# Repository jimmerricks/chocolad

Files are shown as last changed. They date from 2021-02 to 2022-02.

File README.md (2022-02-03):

# Chocolad

The Chocolad is a WIP 3x5+3 split column stagger keyboard based on the [Corne Chocolate](https://github.com/foostan/crkbd/blob/master/corne-chocolate/doc/buildguide_en.md) and the [chocorne](https://github.com/davidphilipbarr/36keys/tree/master/42Keys/chocorne).

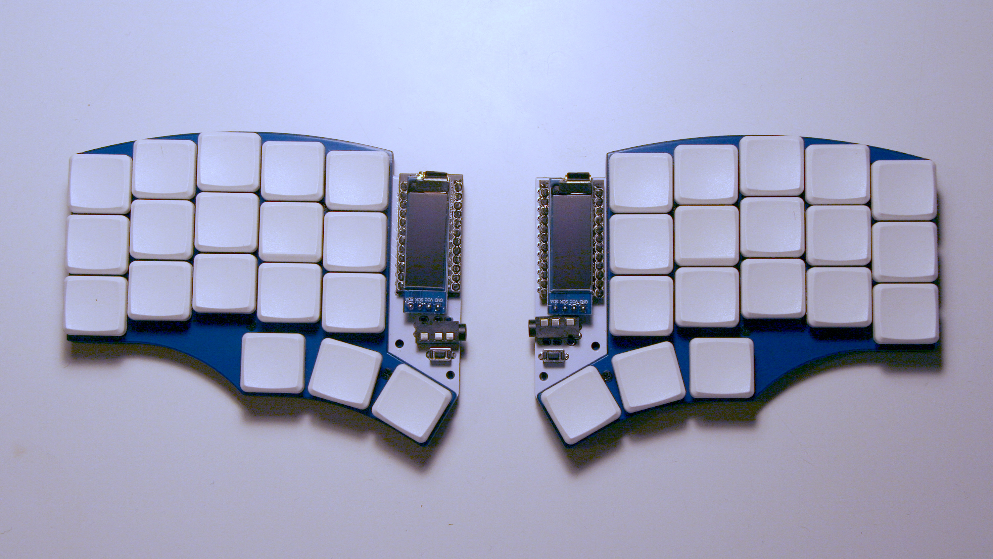
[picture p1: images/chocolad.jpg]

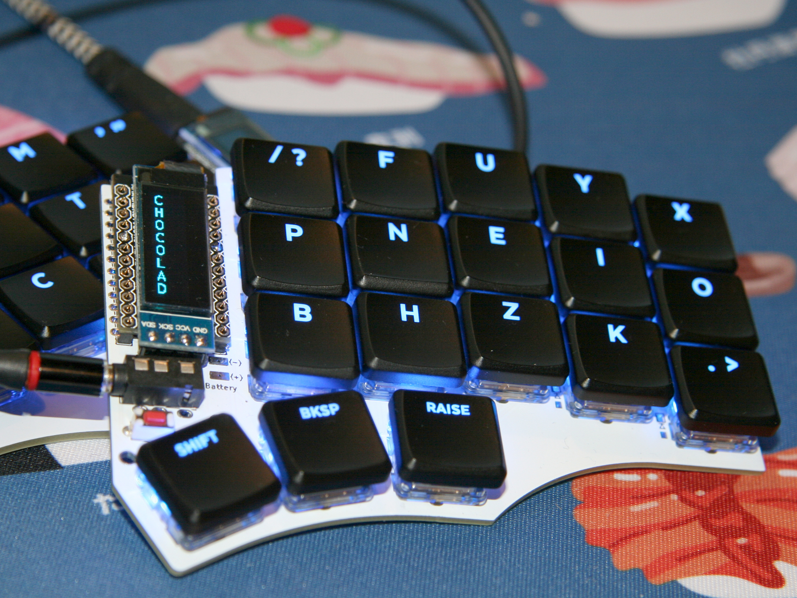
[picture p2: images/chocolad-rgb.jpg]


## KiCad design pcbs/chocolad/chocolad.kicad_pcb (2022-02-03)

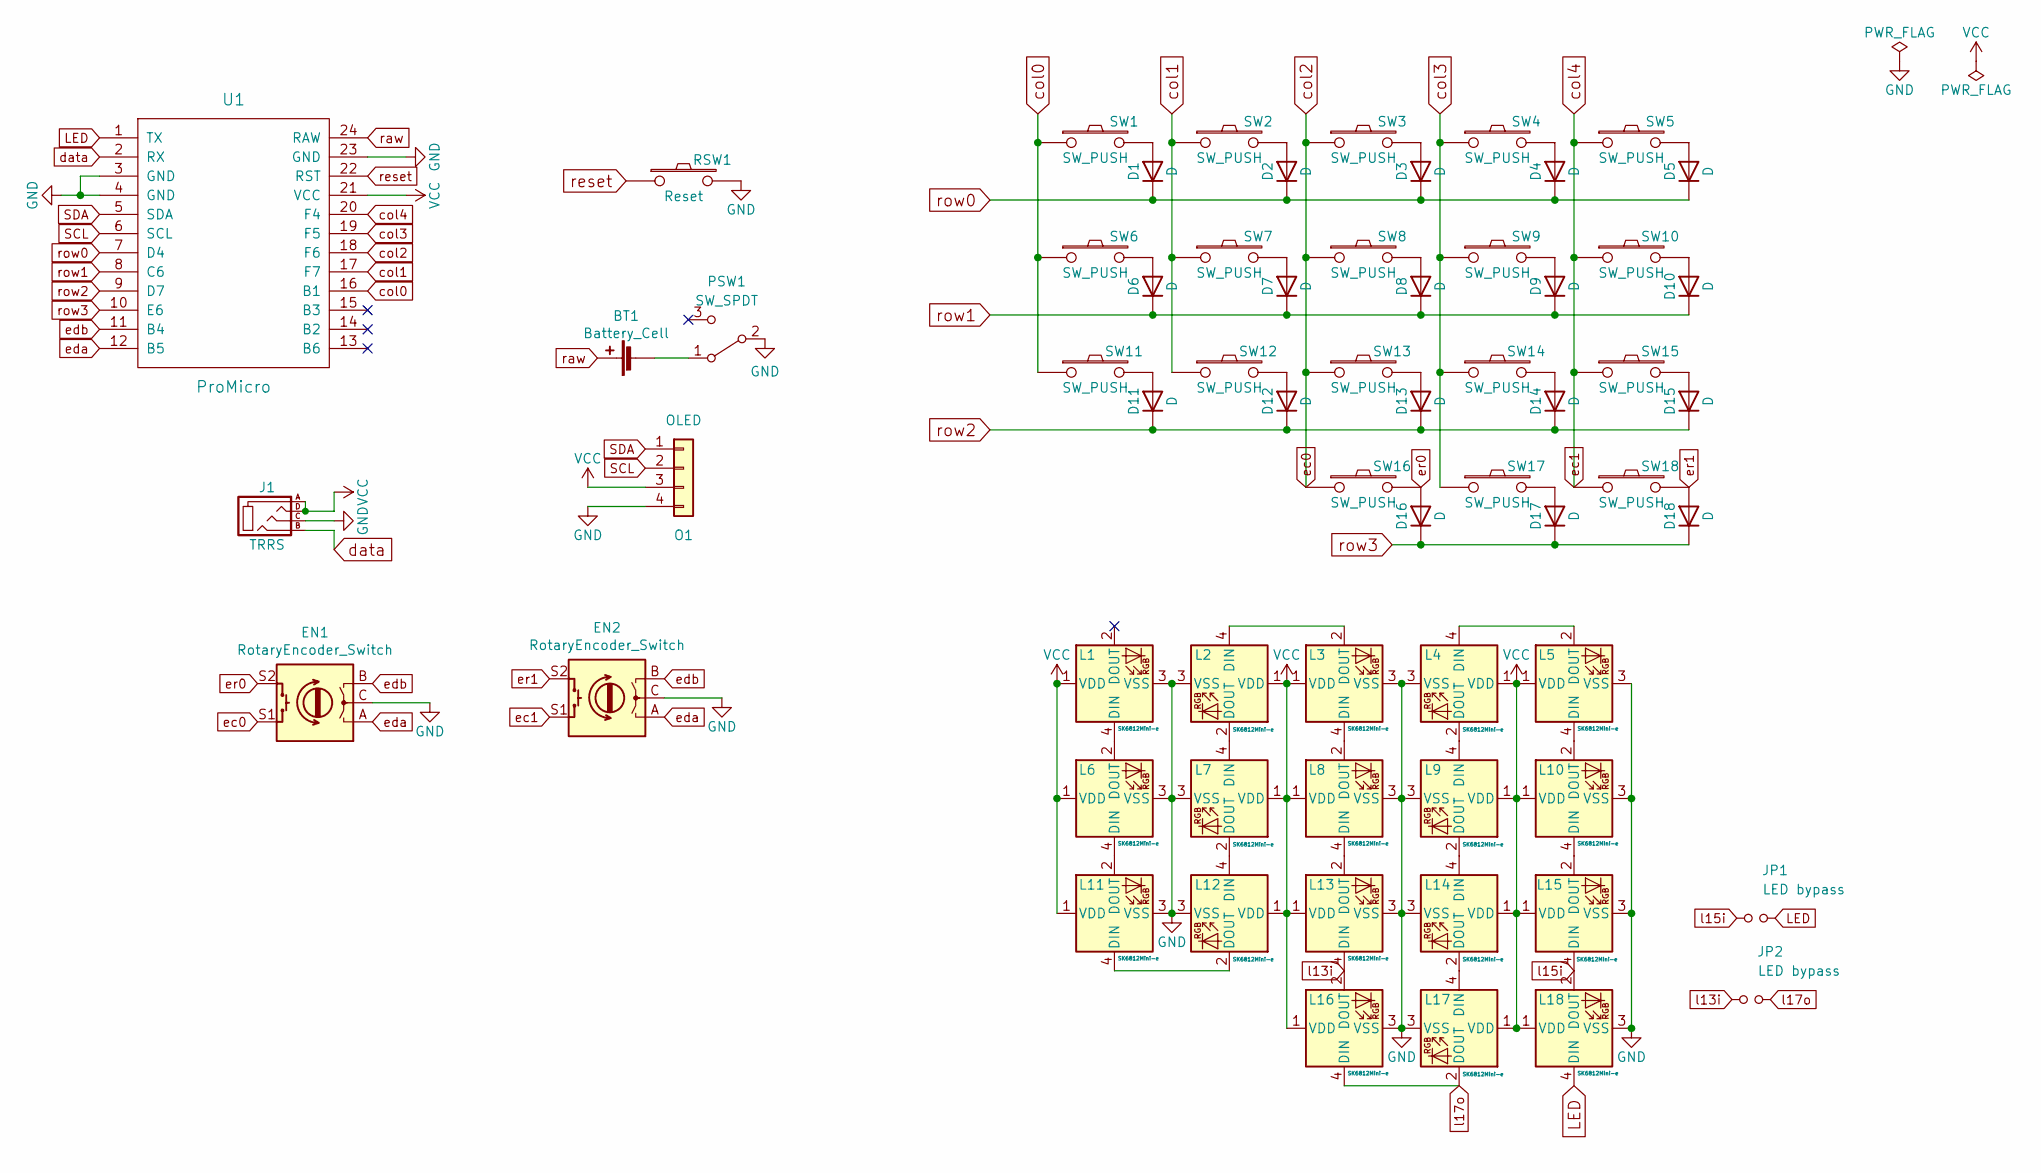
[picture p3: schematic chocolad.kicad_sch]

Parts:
BT1: Battery_Cell; Battery_pads
D1, D2, D3, D4, D5, D6, D7, D8, D9, D10, D11, D12, D13, D14, D15, D16, D17, D18: D; D3_SMD
EN1, EN2: RotaryEncoder_Switch; RotaryEncoder
J1: TRRS
JP1, JP2: LED bypass; Jumper
L1, L2, L3, L4, L5, L6, L7, L8, L9, L10, L11, L12, L13, L14, L15, L16, L17, L18: SK6812Mini-e; SK6812_Mini_E; JLCPCB BOM 0
O1: OLED
PSW1: SW_SPDT; Power
RSW1: Reset
SW1, SW2, SW3, SW4, SW5, SW6, SW7, SW8, SW9, SW10, SW11, SW12, SW13, SW14, SW15, SW16, SW17, SW18: SW_PUSH; Choc
U1: ProMicro

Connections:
GND: EN1.C, EN2.C, J1.C, L1.3 (VSS), L2.3 (VSS), L3.3 (VSS), L4.3 (VSS), L5.3 (VSS), L6.3 (VSS), L7.3 (VSS), L8.3 (VSS), L9.3 (VSS), L10.3 (VSS), L11.3 (VSS), L12.3 (VSS), L13.3 (VSS), L14.3 (VSS), L15.3 (VSS), L16.3 (VSS), L17.3 (VSS), L18.3 (VSS), O1.4, PSW1.2 (B), RSW1.2, U1.3 (GND), U1.4 (GND), U1.23 (GND)
LED: JP1.1, L18.4 (DIN), U1.1 (TX)
unnamed: BT1.2 (-), PSW1.1 (A)
unnamed: D1.2 (A), SW1.2
unnamed: D2.2 (A), SW2.2
unnamed: D3.2 (A), SW3.2
unnamed: D4.2 (A), SW4.2
unnamed: D5.2 (A), SW5.2
unnamed: D6.2 (A), SW6.2
unnamed: D7.2 (A), SW7.2
unnamed: D8.2 (A), SW8.2
unnamed: D9.2 (A), SW9.2
unnamed: D10.2 (A), SW10.2
unnamed: D11.2 (A), SW11.2
unnamed: D12.2 (A), SW12.2
unnamed: D13.2 (A), SW13.2
unnamed: D14.2 (A), SW14.2
unnamed: D15.2 (A), SW15.2
unnamed: D17.2 (A), SW17.2
unnamed: L1.4 (DIN), L6.2 (DOUT)
unnamed: L2.2 (DOUT), L7.4 (DIN)
unnamed: L2.4 (DIN), L3.2 (DOUT)
unnamed: L3.4 (DIN), L8.2 (DOUT)
unnamed: L4.2 (DOUT), L9.4 (DIN)
unnamed: L4.4 (DIN), L5.2 (DOUT)
unnamed: L5.4 (DIN), L10.2 (DOUT)
unnamed: L10.4 (DIN), L15.2 (DOUT)
unnamed: L6.4 (DIN), L11.2 (DOUT)
unnamed: L11.4 (DIN), L12.2 (DOUT)
unnamed: L7.2 (DOUT), L12.4 (DIN)
unnamed: L8.4 (DIN), L13.2 (DOUT)
unnamed: L14.2 (DOUT), L17.4 (DIN)
unnamed: L9.2 (DOUT), L14.4 (DIN)
SCL: O1.2, U1.6 (SCL)
SDA: O1.1, U1.5 (SDA)
VCC: J1.A, J1.D, L1.1 (VDD), L2.1 (VDD), L3.1 (VDD), L4.1 (VDD), L5.1 (VDD), L6.1 (VDD), L7.1 (VDD), L8.1 (VDD), L9.1 (VDD), L10.1 (VDD), L11.1 (VDD), L12.1 (VDD), L13.1 (VDD), L14.1 (VDD), L15.1 (VDD), L16.1 (VDD), L17.1 (VDD), L18.1 (VDD), O1.3, U1.21 (VCC)
col0: SW1.1, SW6.1, SW11.1, U1.16 (B1)
col1: SW2.1, SW7.1, SW12.1, U1.17 (F7)
col2: EN1.S1, SW3.1, SW8.1, SW13.1, SW16.1, U1.18 (F6)
col3: SW4.1, SW9.1, SW14.1, SW17.1, U1.19 (F5)
col4: EN2.S1, SW5.1, SW10.1, SW15.1, SW18.1, U1.20 (F4)
data: J1.B, U1.2 (RX)
eda: EN1.A, EN2.A, U1.12 (B5)
edb: EN1.B, EN2.B, U1.11 (B4)
er0: D16.2 (A), EN1.S2, SW16.2
er1: D18.2 (A), EN2.S2, SW18.2
l13i: JP2.2, L13.4 (DIN), L16.2 (DOUT)
l15i: JP1.2, L15.4 (DIN), L18.2 (DOUT)
l17o: JP2.1, L16.4 (DIN), L17.2 (DOUT)
raw: BT1.1 (+), U1.24 (RAW)
reset: RSW1.1, U1.22 (RST)
row0: D1.1 (K), D2.1 (K), D3.1 (K), D4.1 (K), D5.1 (K), U1.7 (D4)
row1: D6.1 (K), D7.1 (K), D8.1 (K), D9.1 (K), D10.1 (K), U1.8 (C6)
row2: D11.1 (K), D12.1 (K), D13.1 (K), D14.1 (K), D15.1 (K), U1.9 (D7)
row3: D16.1 (K), D17.1 (K), D18.1 (K), U1.10 (E6)

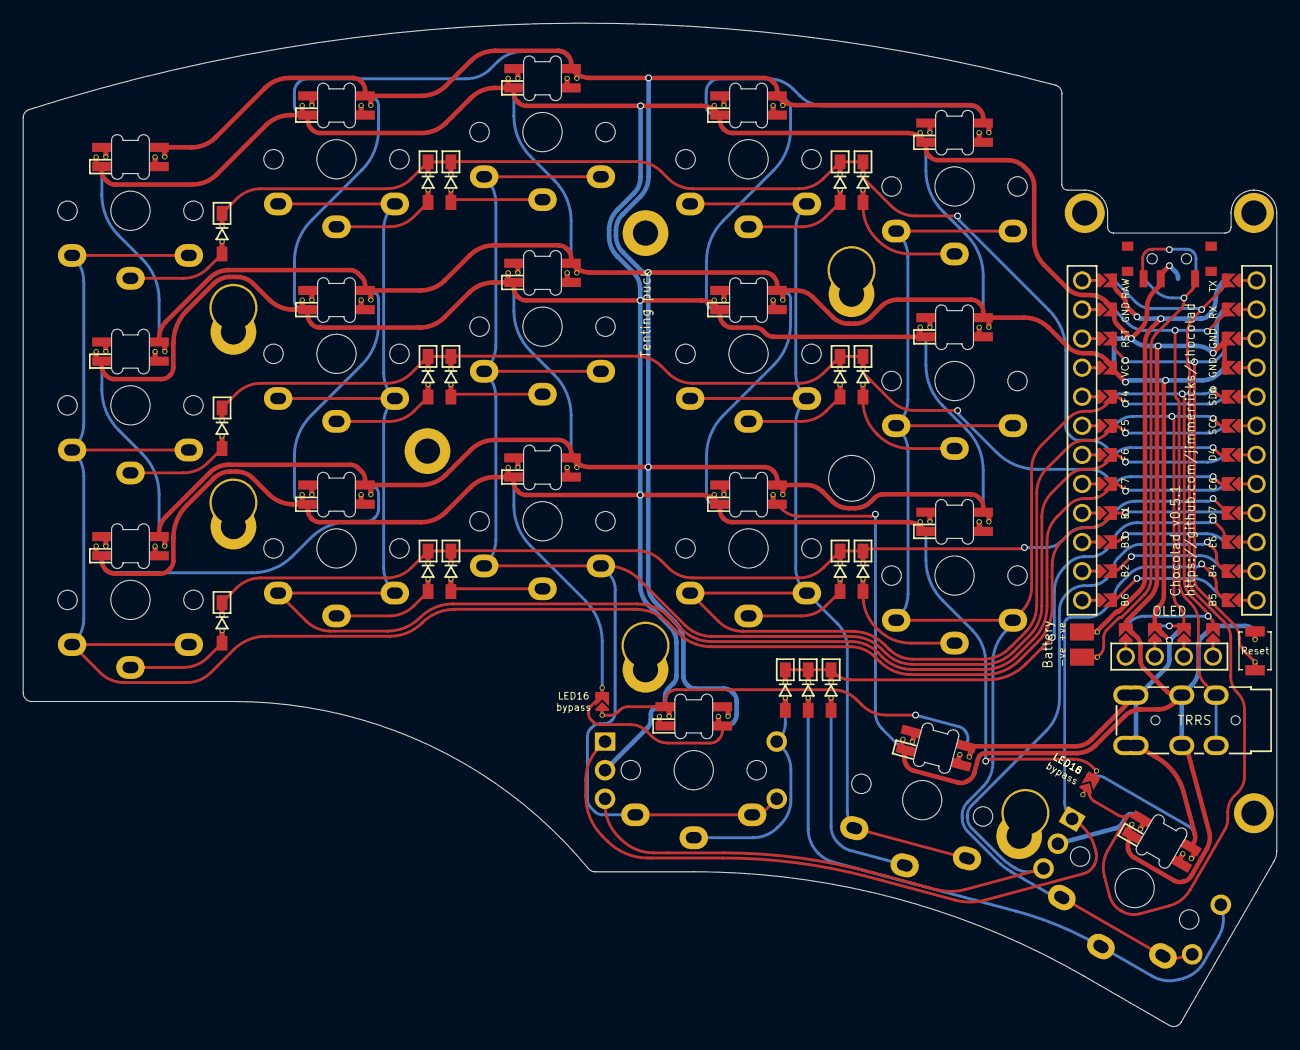
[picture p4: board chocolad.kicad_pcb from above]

Board: 2 copper layers, 109.5 x 87.7 mm, 73 parts (0 on the bottom side), 55 nets.

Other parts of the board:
H1, H2, H3, H5: M2 Hole; M2_double_hole_4mm
H4: M2_double_hole_4mm
PUCK1: SYM_Arrow45_Small; Tenting_puck
Ref**: Val**; M2_hole_3.5mm
Ref**#2, Ref**#3: Val**; M2_hole_3.5mm

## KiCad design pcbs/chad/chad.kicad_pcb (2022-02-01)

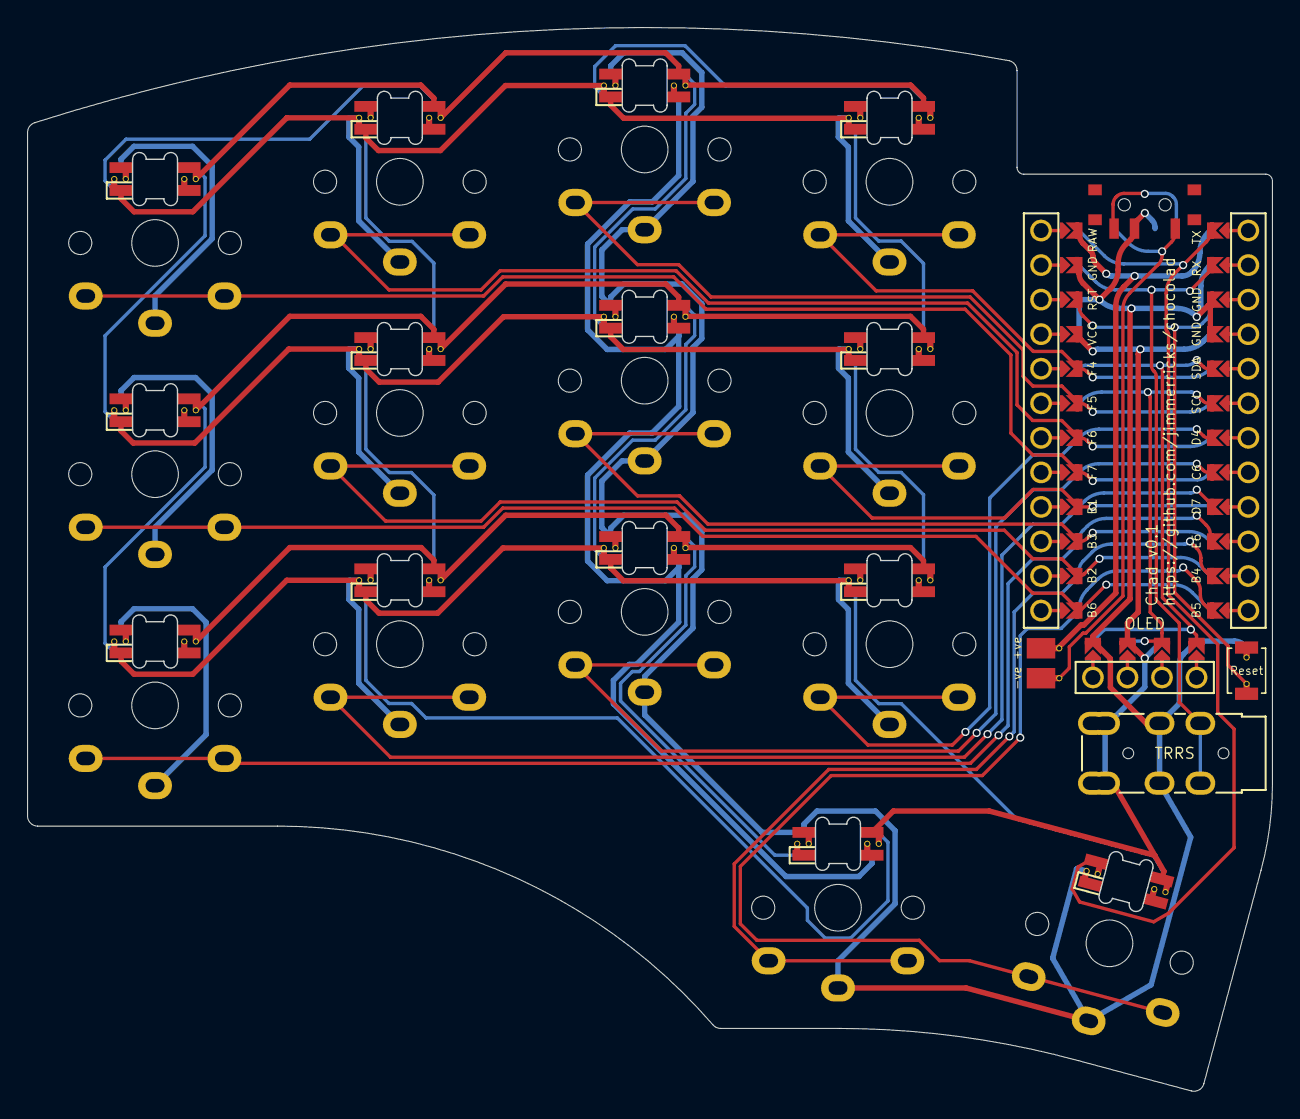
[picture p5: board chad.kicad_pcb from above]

Board: 2 copper layers, 91.5 x 78.2 mm, 34 parts (0 on the bottom side), 36 nets.

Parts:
BT1: Battery_Cell; Battery_pads
J1: TRRS
L1: SK6812Mini-e; SK6812_Mini_E
L2, L3, L4, L5, L6, L7, L8, L9, L10, L11, L12, L13, L14: SK6812Mini-e; SK6812_Mini_E_edit
O1: OLED
PSW1: SW_SPDT; Power
RSW1: Reset
SW1, SW2, SW3, SW4, SW5, SW6, SW7, SW8, SW9, SW10, SW11, SW12, SW13, SW14: SW_PUSH; Choc
U1: ProMicro

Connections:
GND: J1.C, L1.3 (VSS), L2.3 (VSS), L3.3 (VSS), L4.3 (VSS), L5.3 (VSS), L6.3 (VSS), L7.3 (VSS), L8.3 (VSS), L9.3 (VSS), L10.3 (VSS), L11.3 (VSS), L12.3 (VSS), L13.3 (VSS), L14.3 (VSS), O1.4, PSW1.2 (B), RSW1.2, SW1.2, SW2.2, SW3.2, SW4.2, SW5.2, SW6.2, SW7.2, SW8.2, SW9.2, SW10.2, SW11.2, SW12.2, SW13.2, SW14.2, U1.3 (GND), U1.4 (GND), U1.23 (GND)
LED: L14.4 (DIN), U1.1 (TX)
unnamed: BT1.2 (-), PSW1.1 (A)
unnamed: L1.2 (DOUT), L5.4 (DIN)
unnamed: L1.4 (DIN), L2.2 (DOUT)
unnamed: L2.4 (DIN), L6.2 (DOUT)
unnamed: L3.2 (DOUT), L7.4 (DIN)
unnamed: L3.4 (DIN), L4.2 (DOUT)
unnamed: L4.4 (DIN), L8.2 (DOUT)
unnamed: L5.2 (DOUT), L9.4 (DIN)
unnamed: L6.4 (DIN), L10.2 (DOUT)
unnamed: L10.4 (DIN), L13.2 (DOUT)
unnamed: L11.2 (DOUT), L13.4 (DIN)
unnamed: L7.2 (DOUT), L11.4 (DIN)
unnamed: L8.4 (DIN), L12.2 (DOUT)
unnamed: L12.4 (DIN), L14.2 (DOUT)
SCL: O1.2, U1.6 (SCL)
SDA: O1.1, U1.5 (SDA)
VCC: J1.A, J1.D, L1.1 (VDD), L2.1 (VDD), L3.1 (VDD), L4.1 (VDD), L5.1 (VDD), L6.1 (VDD), L7.1 (VDD), L8.1 (VDD), L9.1 (VDD), L10.1 (VDD), L11.1 (VDD), L12.1 (VDD), L13.1 (VDD), L14.1 (VDD), O1.3, U1.21 (VCC)
data: J1.B, U1.2 (RX)
raw: BT1.1 (+), U1.24 (RAW)
reset: RSW1.1, U1.22 (RST)
switch1: SW1.1, U1.17 (F7)
switch2: SW2.1, U1.18 (F6)
switch3: SW3.1, U1.19 (F5)
switch4: SW4.1, U1.20 (F4)
switch5: SW5.1, U1.13 (B6)
switch6: SW6.1, U1.14 (B2)
switch7: SW7.1, U1.15 (B3)
switch8: SW8.1, U1.16 (B1)
switch9: SW9.1, U1.10 (E6)
switch10: SW10.1, U1.9 (D7)
switch11: SW11.1, U1.8 (C6)
switch12: SW12.1, U1.7 (D4)
switch13: SW13.1, U1.11 (B4)
switch14: SW14.1, U1.12 (B5)

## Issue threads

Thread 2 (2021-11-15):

Parts List

drewfowler, 2021-11-15:
Hello Jim! This board looks amazing and I really want to build it. Any chance you have a parts list so that I can order parts before I just order PCBs?

KostkaBrukowa, 2021-11-16:
I looked into the schema and I think you will need:
PCB | 2 pieces |  
Pro Micro | 2 |  
TRRS Jack | 2 |  
Tactile switch | 2 pieces |  
Diode | 36 pieces | Compatible with chip components only
Key switch | 36 pieces | Compatible with Choc (low profile) only
Key-caps | 36 | 1u
OLED module | 2 pieces |  Optional
4 pin headers | 2 |  
4 pin sockets | 2 |  
Cushion rubber | 8 pieces |  
TRS (3 pole) cable | 1 | TRRS (4 pole) cable also available
Micro USB Cable

Taken from here: https://github.com/foostan/crkbd/blob/main/corne-chocolate/doc/buildguide_en.md
Only thing I don't know its if the board uses SK6812MINI or SK6812MINI-e

jimmerricks, 2021-11-16:
Thanks Kostka. This looks right. I will add a few notes towards a long ago promised BOM and build guide.

The PCBs are reversible and can be ordered cheaply from JLCPCB or for free from AllPCB (as part of a currently running promotion). The switch and base plates are similarly reversible, but are optional. I have found 1.2mm thickness to work well for them. You may have to pay a surcharge to have the switch plate printed by JLCPCB. OLED covers (also optional) are the same as those for the Corne (which can be ordered or cut from a few places), but it's a tight fit.

The diode type is 1N4148W with the SOD123 package. These are smallish, surface mount components, which need to be mounted with the cathode (usually a thin line) on the side of the square. If you haven't soldered SMT components before, don't worry, it is not too hard. Just make sure you have a decent soldering iron and a decent lead-based solder. The TRRS jacks (PJ-320A) and reset switches (2 pin DIP switches) are through hole components and dead easy to solder.

Pro micros or any alternative (elite-c, nice!nano, etc) will work. These can be mounted facing upwards or downwards. Just make sure that the TX pin goes in the TX hole on the PCB. Be careful here. These are very hard to desolder. Socketing is always a good option, not least because it makes them easier to reuse.

OLEDs (2x SSD1306 128X32) and LEDs (36x SK6812MINI-e) are optional. If you use OLEDs, bridge the jumpers on the top of the board. Again, these are hard to desolder, so may be worth socketing. The LEDs are the trickiest thing to solder in the build. They are mounted in a downwards facing direction on the bottom of the PCB, so that they shine up through the board and through the switch. Do line up the chamfer with the square. Do use liberal amounts of solder flux. Don't use a soldering iron temperature above 300C. Don't hold your iron on the LED leg for more than a second.

Switches are Kailh Chocs (1350). They are tightly spaced so won't work with all Choc stem keycaps. I recommend MBK profile.

Finally, if you do go with plates, you will need 10x 4mm M2 spacers and 20x 3mm M2 screws. Bumpons are also nice, but people use all kinds of things.

The [Corne build guide](https://github.com/foostan/crkbd/blob/main/corne-chocolate/doc/buildguide_en.md) is good. Also check out the guide for the [Sofle](https://josefadamcik.github.io/SofleKeyboard/) and, for the LEDs, the [YAEMK](https://karlk90.github.io/yaemk-split-kb/#correct-orientation-of-rgb-leds) guide is handy.

jimmerricks, 2021-11-16:
Alternatively, I have a kit or two left over if you want one.

drewfowler, 2021-11-16:
Thanks for the response. I ordered everything earlier today and did standard 1.6mm for pcbs. So we will see how they turn out.
I appreciate the help and am looking forward to building it!

jimmerricks, 2021-11-16:
No worries. Please send me a picture when you are done and I hope that you enjoy the keyboard.

Closed 2021-11-16.

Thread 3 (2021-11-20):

PCB won't open in KiCad v5.1.10 through 5.1.12

hmngwy, 2021-11-20:
I also tried opening this with fresh installs (uninstall then install instead of just reinstalls) to no avail.

It would just say it needs a version from October in pcbview, and show's a syntax error in KiCad.

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

```
2:03:50 AM: file 'C:\Users\x\Downloads\chocolad-main\chocolad-main\pcb\chocolad.kicad_pro', line 1: '=' expected.
```

Other projects open just fine.

hmngwy, 2021-11-20:
Nevermind I seem to be having the same issue with other projects that are made with these versions.

jimmerricks, 2021-11-20:
It is Kicad nightly only I am afraid. I can export the schematic if that is all you need.

Closed 2021-11-20.

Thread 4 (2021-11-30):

QMK Folder

drewfowler, 2021-11-30:
I am curious if you can share your QMK folder? I thought it would be worth it to reach out before I do too much digging. I uploaded the dracula code from qmk but the buttons are all mirrored. Thanks

jimmerricks, 2021-11-30:
You can help me do some testing. The following may or may not work (I was only interested in testing the LEDs) and it needs a better default keymap. Let me know if there are any problems with it.

* [chocolad_rgb.zip](https://github.com/jimmerricks/chocolad/files/7623246/chocolad_rgb.zip)

jimmerricks, 2021-11-30:
To get this to work you will need to (at the very least) disable the OLED in the default keymap rules.mk or else ammend the code. I compiled this under an old version of QMK.

jimmerricks, 2021-12-02:
How'd you get on with this?

drewfowler, 2021-12-02:
I only got about 30 minutes with it last night but, I just deleted all the files in the default folder but keymap.c and enabled LEDs in the top level rules and it worked. I have only built up one side but it seemed to work great off that. So I will continue building off of that. Thank you!

jimmerricks, 2021-12-02:
No worries. Good to hear that the OLED is the only thing.

Closed 2021-12-02.

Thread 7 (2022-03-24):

Hotswap

andrewneyman, 2022-03-24:
Not really an issue, just wondering if a hotswap version is planned.

jimmerricks, 2022-03-24:
I plan to make the holes compatible with Mill Max sockets, but not (at this stage) Kailh hotswap sockets.

maverick1872, 2022-11-07:
Thanks for the update. If you're alright with it I may just see if I can modify it sufficiently myself then as I'd ideally have a 6 col variant personally.

Closed 2022-03-24.

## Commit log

2021-02-07 Initial commit of chocolad files.
    [chocolad-base.kicad_pcb, chocolad-plate.kicad_pcb, chocolad.dsn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]
2021-11-11 Updated the repository to Chocolad RGB. README to follow.
    [chocolad-base-plate.kicad_pcb, chocolad-base.kicad_pcb, chocolad-plate.kicad_pcb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]
2022-01-21 Reorganised directories for different pcb versions.
    [chocolad.kicad_pcb, chocolad.kicad_sch, chocolad.sch]
2022-01-21 Updated the sk6812 and battery pad footprints.
    [chocolad.kicad_pcb]
2022-01-22 Added and changed components and altered shape.
    [chocolad.kicad_pcb, chocolad.kicad_sch]
2022-01-25 Removed non-compatible files for version upgrade.
    [chocolad-base-plate.kicad_pcb, chocolad-switch-plate.kicad_pcb]
2022-01-28 Finalised traces.
    [chocolad.kicad_pcb, chocolad.kicad_sch]
2022-01-30 Moved footprints into local library.
    [chocolad.kicad_pcb, chocolad.kicad_sch]
2022-02-01 Add the 28 key Chad keyboard.
    [chad.kicad_pcb, chad.kicad_sch, chad.sch]
2022-02-03 Fixed the cover
    [chocolad.kicad_pcb, chocolad.kicad_sch]
